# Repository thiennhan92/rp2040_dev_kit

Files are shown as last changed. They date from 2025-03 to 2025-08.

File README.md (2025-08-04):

# RP2040 Development Board

This is a custom development board based on the Raspberry Pi RP2040 microcontroller. It integrates essential peripherals for embedded systems prototyping, including USB, Ethernet, RGB LEDs, sensors, and storage. The design is accompanied by validated firmware that supports all core hardware features.

---
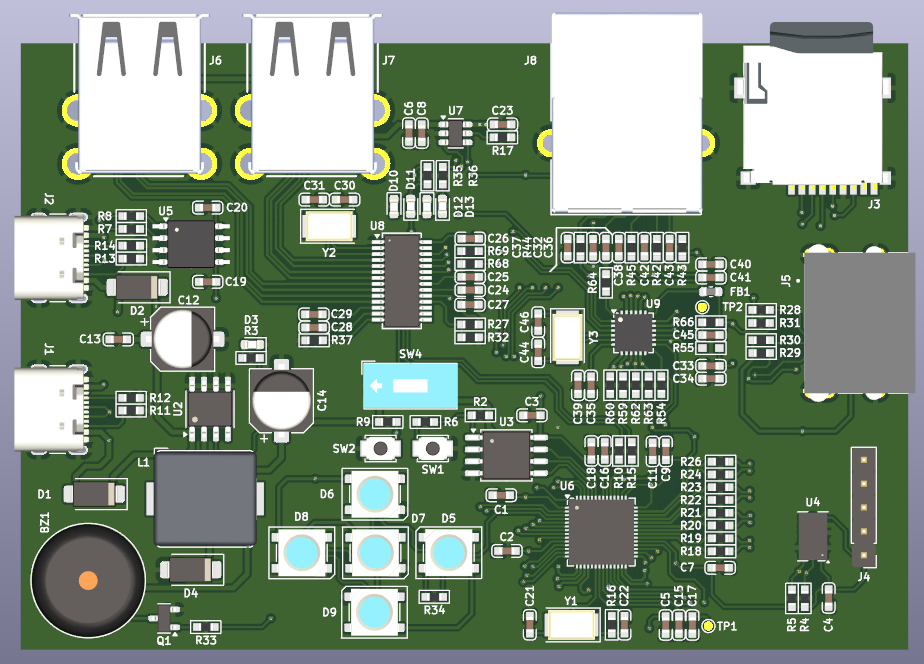
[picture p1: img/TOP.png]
RP2040 Dev Kit - Top View

## 🧩 Features

- **Microcontroller**: Raspberry Pi RP2040 (dual-core ARM Cortex-M0+)
- **Power Management**:
  - XL1509-3.3 Buck Converter
  - CH217K USB Power Switch
- **USB Interface**:
  - CH340N USB-to-Serial
  - Dual USB ports for host and device roles
- **Networking**:
  - LAN8720A Ethernet PHY (RMII)
  - RJ45 connector (HR911105A)
- **Storage**:
  - MicroSD card 
  - W25Q128FV QSPI Flash
- **Sensors**:
  - ADXL345 3-Axis Accelerometer (I²C/SPI configurable)
- **User Interface**:
  - Daisy-chained WS2812-compatible RGB LEDs
  - Onboard buzzer
  - Status LEDs (Ethernet activity)
- **Debugging**:
  - SWD interface
  - USB bootloader support
- **Expansion**:
  - HDMI-style connector (repurposed for GPIO)
  - Multiple GPIO headers and DIP switches

---

## ✅ Firmware Validation

The firmware has been **fully validated** and supports all major board features.  
*(Please check with Arduino and Pico SDK examples)*

The firmware has been fully validated and supports all major board features:

- [x] **USB Host/Device** – Detection and communication
- [x] **Ethernet** – Connectivity via LAN8720A
- [x] **MicroSD** – FAT filesystem read/write
- [x] **RGB LEDs** – WS2812-compatible LED control
- [x] **ADXL345** – Sensor readout over I²C
- [x] **QSPI Flash** – W25Q128FV access
- [x] **Buzzer & GPIO** – Output control and signal handling
- [x] **HDMI** - Digital video signal rendering tested
- [x] **Bootloader & SWD** – Debugging and firmware upload

© 2025 – RP2040 Dev Board Project. All rights reserved.

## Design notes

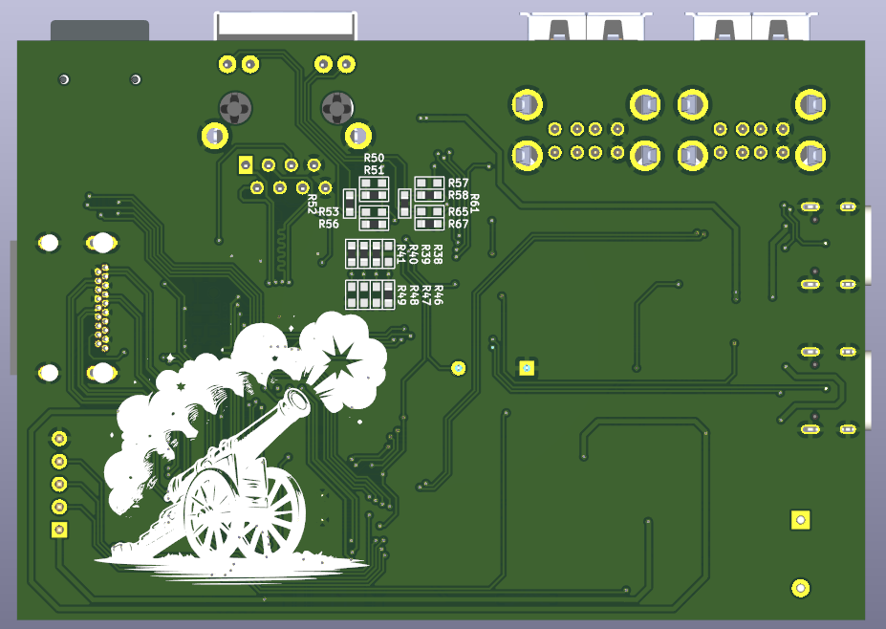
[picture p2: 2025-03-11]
img/BOT.png

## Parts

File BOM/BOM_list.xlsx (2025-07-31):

Id | Designator | Footprint | Quantity | Designation
1 | SW2,SW1 | SW_SPST_B3U-1000P | 2 | SW_SPST_3x4mm | https://www.thegioiic.com/nut-nhan-3x4mm-cao-2-5mm-2-chan-smd
2 | Y2,Y1 | Crystal_SMD_5032-2Pin_5.0x3.2mm | 2 | 12MHz
3 | Y3 | Crystal_SMD_5032-2Pin_5.0x3.2mm | 1 | 25MHz
4 | BZ1 | Buzzer_12x9.5RM7.6 | 1 | Buzzer 1209
5 | L1 | L_Bourns_SRP1038C_10.0x10.0mm | 1 | CDRH104/68uH
6 | Q1 | SOT-23 | 1 | SI2300DS
7 | SW4 | SW_DIP_01_Slide_W7.62mm_P2.54mm | 1 | SW_DIP_x01
8 | FB1 | L_0603_1608Metric | 1 | CBG160808U601T
9 | U2 | SOIC-8_3.9x4.9mm_P1.27mm | 1 | XL1509-3.3
10 | U3 | SOIC-8_5.23x5.23mm_P1.27mm | 1 | W25Q128FVSG
11 | U4 | LGA-14_3x5mm_P0.8mm | 1 | ADXL345
12 | U5 | SOP-8_3.9x4.9mm_P1.27mm | 1 | CH340N
13 | U6 | QFN-56-1EP_7x7mm_P0.4mm | 1 | RP2040
14 | U7 | SOT-23-6 | 1 | CH217K | https://linhkienthuduc.com/san-pham/ch217k-ic-bao-ve-usb-current-limiting-power-distribution-wch/
15 | U8 | SSOP-28_3.9x9.9mm_P0.635mm | 1 | FE1.1s | https://shopee.vn/product/1152770645/24613658217?gad_source=1
16 | U9 | VQFN-24-1EP_4x4mm_P0.5mm | 1 | LAN8720A
17 | J1,J2 | USB_C_Receptacle_GCT_USB4105 | 2 | USB4105-GF-A | https://www.thegioiic.com/cong-usb-cai-3-1-type-c-16-chan-thang-dan-smd
18 | J3 | MiSD-PP-9P-V2 | 1 | Micro_SD_Card | https://www.thegioiic.com/misd-pp-9p-v2-khay-the-nho-microsd-9-chan-push-push
19 | J5 | CNCTECH_2000-1-1-20-00-BK | 1 | 10029449-111RLF | https://www.thegioiic.com/cong-hdmi-cai-type-a-19-chan-vuong-goc
20 | J7,J6 | MOLEX_USB_67298-4090 | 2 | USB1035-GF-P-0-B-B | https://www.thegioiic.com/cong-usb-cai-doi-2-0-type-a-8-chan-cong-90-do
21 | J8 | RJ45_HR911105A | 1 | HR911105A
22 | C32,C26,C15,C5,C23,C28,C19,C3,C16,C33,C1,C2,C45, C11,C7,C27,C4,C6,C9,C20 | C0603_HandSoldering | 20 | C0603/0.1uF
23 | C41,C29,C34,C24,C39,C8,C25 | C0603_HandSoldering | 7 | C0603/10uF
24 | C21,C44,C38,C30,C46,C31,C42,C22,C37,C43 | C0603_HandSoldering | 10 | C0603/10pF
25 | C12,C14 | CP_Elec_6.3x7.7 | 2 | CP/220uH/16V
26 | C18,C17,C13 | C0603_HandSoldering | 3 | C0603/1uF
27 | C36 | C0603_HandSoldering | 1 | C0603/22nF
28 | C40,C35 | C0603_HandSoldering | 2 | C0603/470pF
29 | D1,D4,D2 | D_SMA | 3 | SS34
30 | D8,D9,D7,D6,D5 | LED_WS2812B_PLCC4_5.0x5.0mm | 5 | WS2812B
31 | D10,D13,D12,D3,D11 | LED_0603_1608Metric | 5 | LED_green
32 | R62,R7,R63,R10,R60,R15,R8,R59 | R0603_HandSoldering | 8 | R0603/22R
33 | R34,R24,R18,R19,R28,R26,R20,R22,R23,R21,R56,R67 | R0603_HandSoldering | 12 | R0603/200R
34 | R11,R14,R68,R27,R2,R9,R13,R12,R69,R66,R46,R52, R41,R39,R40,R61 | R0603_HandSoldering | 16 | R0603/5.6K
35 | R29,R36,R30,R31,R37,R35,R4,R5 | R0603_HandSoldering | 8 | R0603/2.7K
36 | R6,R3,R54,R33,R16 | R0603_HandSoldering | 5 | R0603/1K
37 | R64 | R0603_HandSoldering | 1 | R0603/12.1K/1%
38 | R32,R17 | R0603_HandSoldering | 2 | R0603/30.1K/1%
39 | R44,R43,R45,R42 | R0603_HandSoldering | 4 | R0603/49.9R/1%
40 | R58,R51 | R0603_HandSoldering | 2 | R0603/0R
41 | R55,R48,R38,R53,R49,R50,R47,R65,R57 | R0603_HandSoldering | 9 | R0603/NA

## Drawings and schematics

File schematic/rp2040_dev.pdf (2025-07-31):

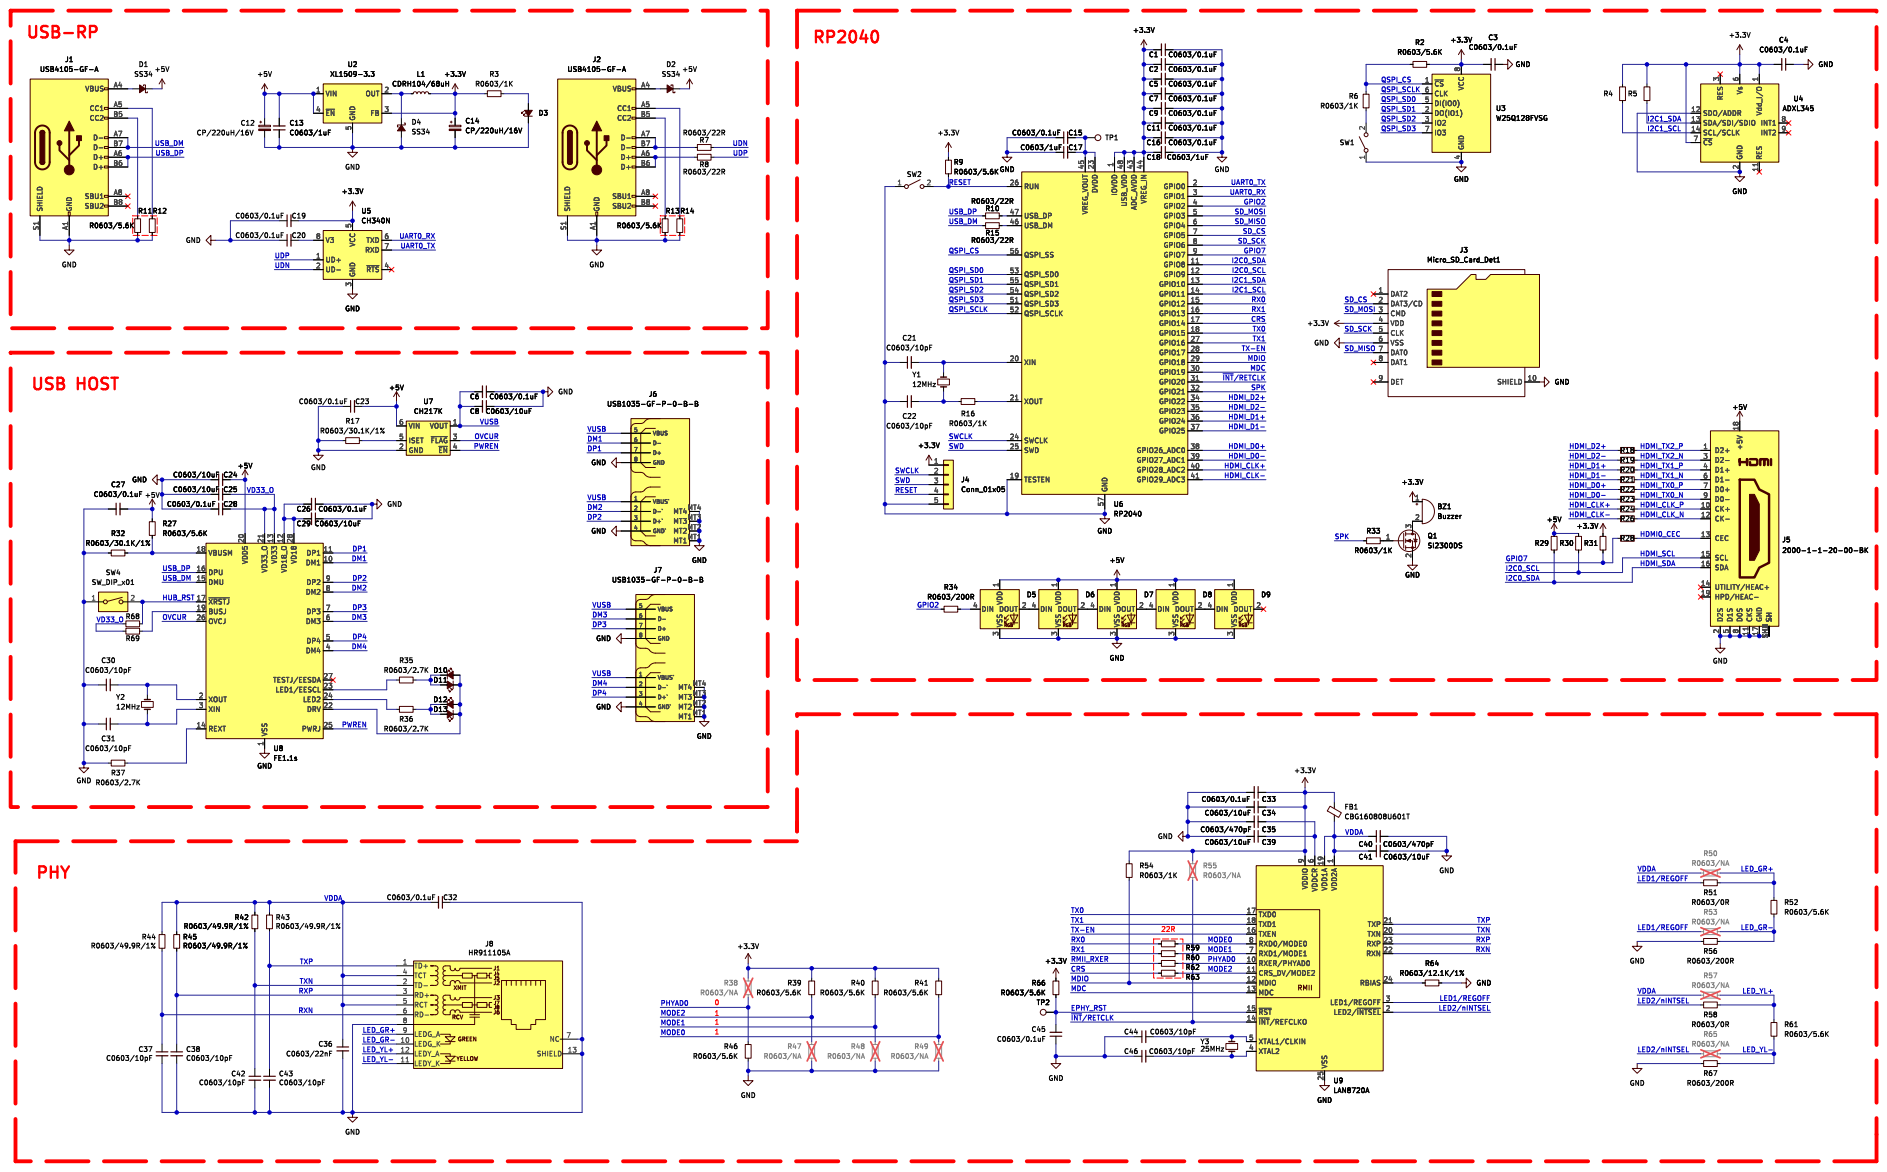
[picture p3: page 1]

3 TXD 6 RXD 7 ~{RTS}4 R13 C14 CP/220uH/16V D3

3 DOUT 2 D8 RMII TXD0 17 TXD1 18 TXEN 16 RXD0/MODE0 8 RXD1/MODE1 7 RXER/PHYAD0 10 CRS_DV/MODE2 11 MDIO 12 MDC 13 ~{RST} 15 ~{INT}/REFCLKO 14 XTAL1/CLKIN 5 XTAL2 4 VDDIO

J8J6 TD+ 1 TCT 4 TD- 2 RD+ 3 RCT 5 RD- 6

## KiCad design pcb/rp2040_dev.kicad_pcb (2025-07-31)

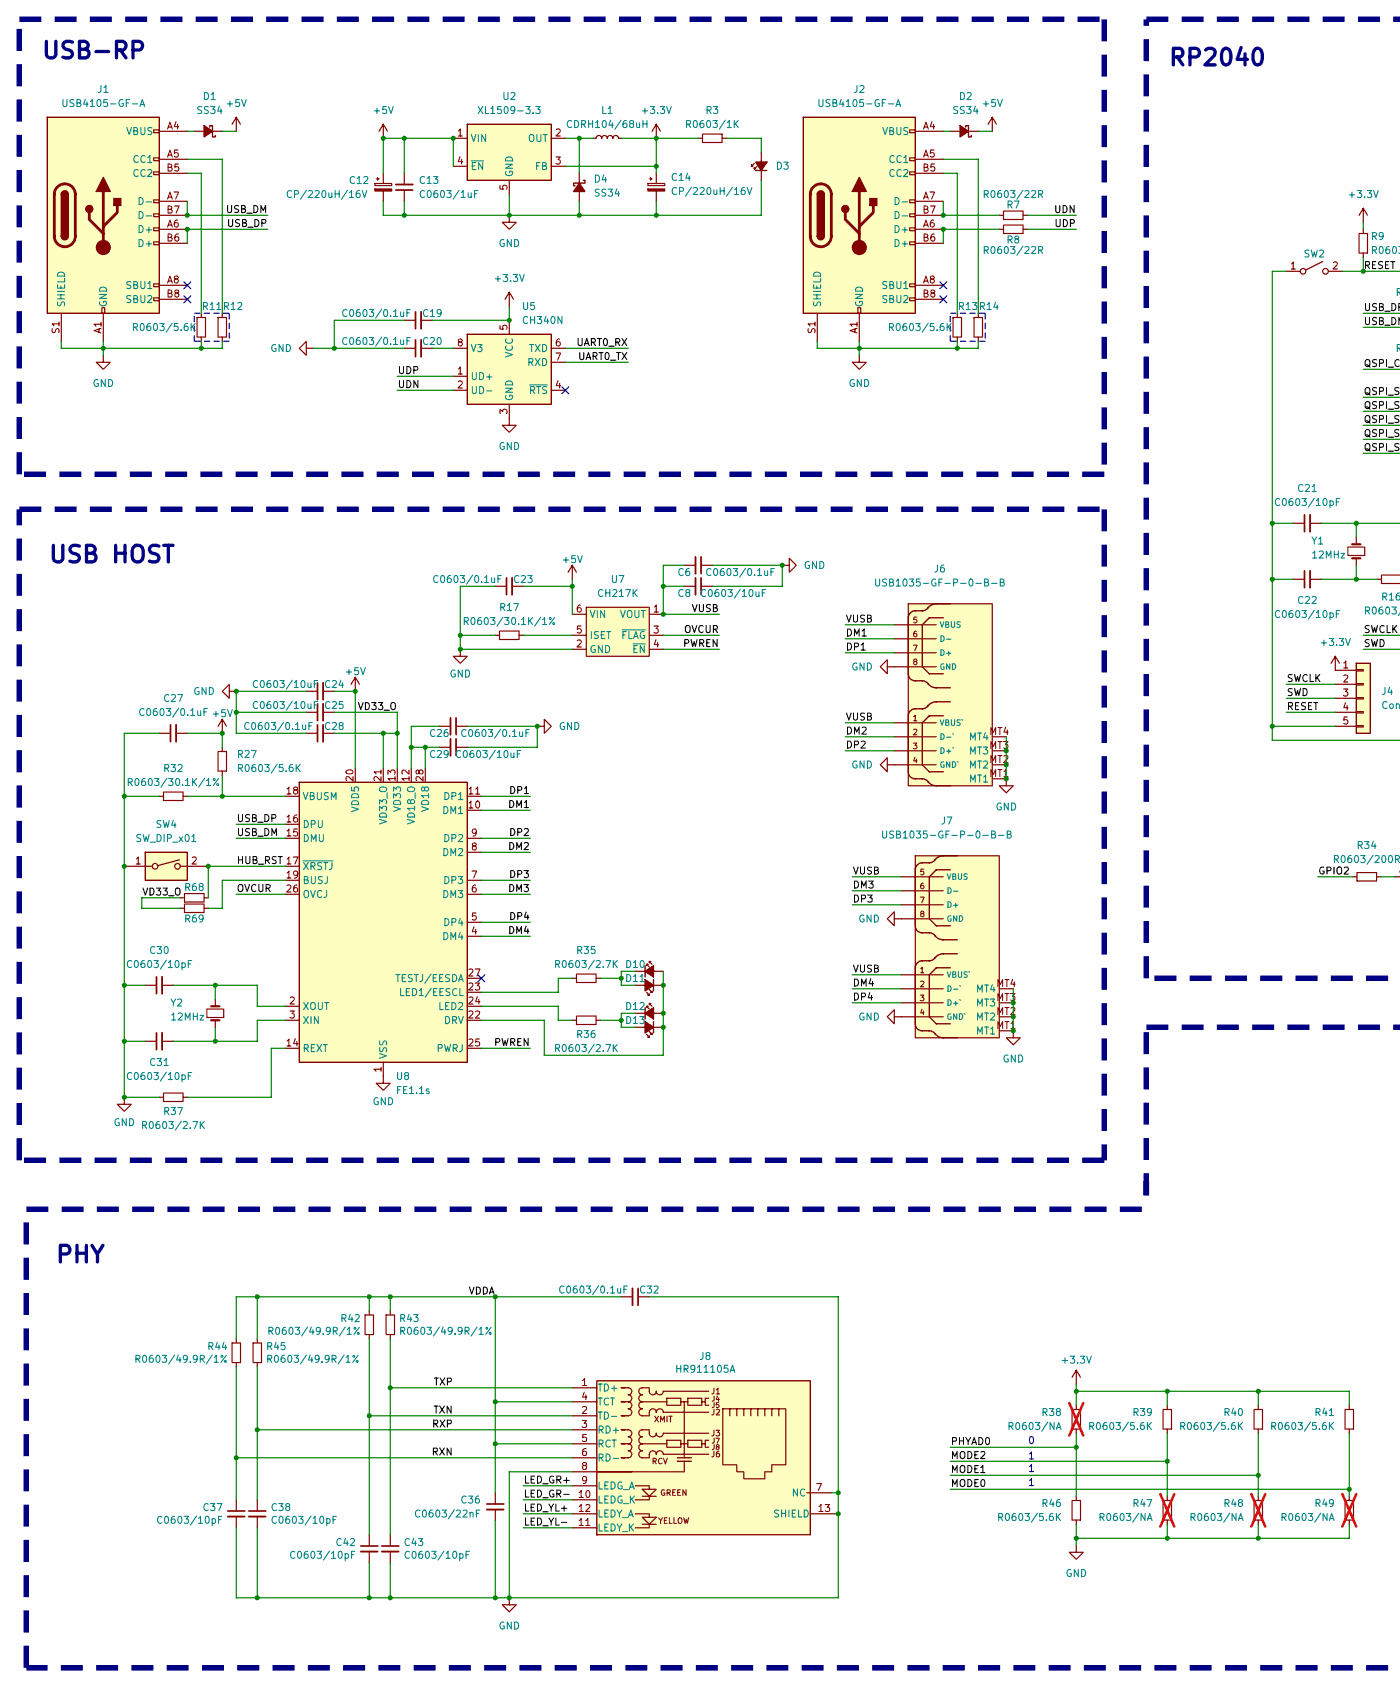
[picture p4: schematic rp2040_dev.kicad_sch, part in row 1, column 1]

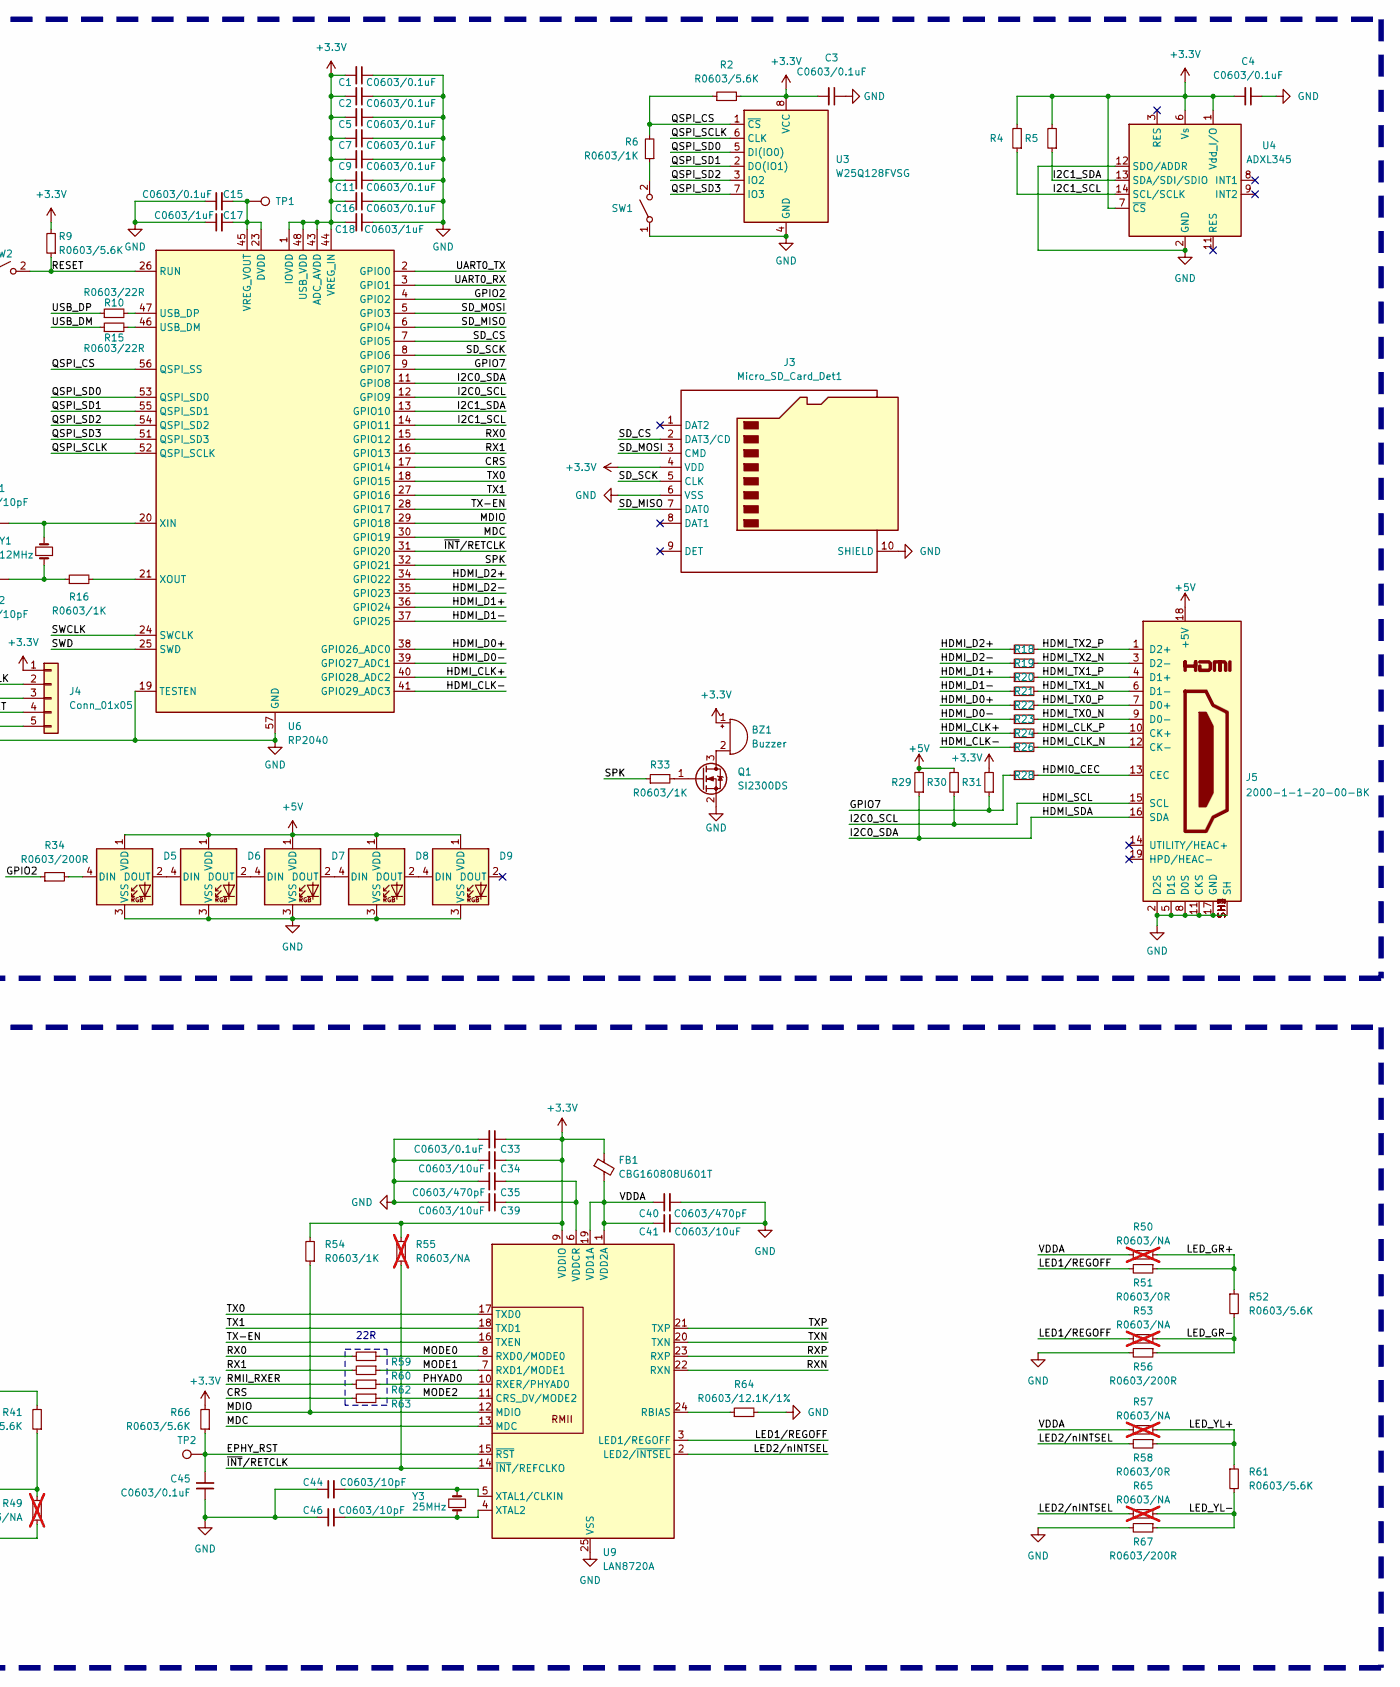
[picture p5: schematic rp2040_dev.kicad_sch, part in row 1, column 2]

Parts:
BZ1: Buzzer; Buzzer_12x9.5RM7.6
C1, C2, C3, C4, C5, C6, C7, C9, C11, C15, C16, C19, C20, C23, C26, C27, C28, C32, C33, C45: C0603/0.1uF; C0603_HandSoldering
C8, C24, C25, C29, C34, C39, C41: C0603/10uF; C0603_HandSoldering
C12, C14: CP/220uH/16V; CP_Elec_6.3x7.7
C13, C17, C18: C0603/1uF; C0603_HandSoldering
C21, C22, C30, C31: C0603/10pF; C0603_HandSoldering; PartNumber 0603N270K250CT
C35, C40: C0603/470pF; C0603_HandSoldering
C36: C0603/22nF; C0603_HandSoldering
C37, C38, C42, C43, C44, C46: C0603/10pF; C0603_HandSoldering
D1, D2, D4: SS34; D_SMA
D3, D10, D11, D12, D13: LED_green; LED_0603_1608Metric
D5, D6, D7, D8, D9: WS2812B; LED_WS2812B_PLCC4_5.0x5.0mm_P3.2mm
FB1: CBG160808U601T; L_0603_1608Metric
J1, J2: USB4105-GF-A; USB_C_Receptacle_GCT_USB4105-xx-A_16P_TopMnt_Horizontal; PartNumber USB4105-GF-A
J3: Micro_SD_Card_Det1; MiSD-PP-9P-V2
J4: Conn_01x05; PinHeader_1x05_P2.54mm_Vertical
J5: 2000-1-1-20-00-BK; CNCTECH_2000-1-1-20-00-BK; PARTREV A
J6, J7: USB1035-GF-P-0-B-B; MOLEX_USB_67298-4090
J8: HR911105A; RJ45_HR911105A
L1: CDRH104/68uH; L_Bourns_SRP1038C_10.0x10.0mm
Q1: SI2300DS; SOT-23; PartNumber SI2302DDS-T1-GE3
R2, R9, R11, R12, R13, R14, R27, R39, R40, R41, R46, R52, R61, R66, R68, R69: R0603/5.6K; R0603_HandSoldering
R3, R6, R16, R33, R54: R0603/1K; R0603_HandSoldering
R4, R5, R29, R30, R31, R35, R36, R37: R0603/2.7K; R0603_HandSoldering
R7, R8, R10, R15, R59, R60, R62, R63: R0603/22R; R0603_HandSoldering
R17, R32: R0603/30.1K/1%; R0603_HandSoldering
R18, R19, R20, R21, R22, R23, R24, R26, R28, R34, R56, R67: R0603/200R; R0603_HandSoldering
R38, R47, R48, R49, R50, R53, R55, R57, R65: R0603/NA; R0603_HandSoldering; not fitted
R42, R43, R44, R45: R0603/49.9R/1%; R0603_HandSoldering
R51, R58: R0603/0R; R0603_HandSoldering
R64: R0603/12.1K/1%; R0603_HandSoldering
SW1, SW2: SW_SPST_3x4mm; SW_SPST_B3U-1000P
SW4: SW_DIP_x01; SW_DIP_SPSTx01_Slide_9.78x4.72mm_W7.62mm_P2.54mm
TP1, TP2: TestPoint; TestPoint_Pad_D1.0mm
U2: XL1509-3.3; SOIC-8_3.9x4.9mm_P1.27mm
U3: W25Q128FVSG; SOIC-8_5.23x5.23mm_P1.27mm; PartNumber W25Q128JVS
U4: ADXL345; LGA-14_3x5mm_P0.8mm_LayoutBorder1x6y
U5: CH340N; SOP-8_3.9x4.9mm_P1.27mm
U6: RP2040; QFN-56-1EP_7x7mm_P0.4mm_EP3.2x3.2mm_ThermalVias; PartNumber RP2040
U7: CH217K; SOT-23-6
U8: FE1.1s; SSOP-28_3.9x9.9mm_P0.635mm
U9: LAN8720A; VQFN-24-1EP_4x4mm_P0.5mm_EP2.5x2.5mm
Y1, Y2: 12MHz; Crystal_SMD_5032-2Pin_5.0x3.2mm
Y3: 25MHz; Crystal_SMD_5032-2Pin_5.0x3.2mm

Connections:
+3.3V: BZ1.1 (-), C1.2, C2.2, C3.2, C4.2, C5.2, C7.2, C9.2, C11.2, C14.1, C16.2, C18.2, C19.2, C33.1, C34.1, FB1.1, J3.4 (VDD), J4.1, L1.2, R2.2, R3.2, R4.2, R5.2, R9.2, R31.2, R38.2, R39.2, R40.2, R41.2, R54.2, R55.2, R66.2, U2.3 (FB), U3.8 (VCC), U4.1 (Vdd_I/O), U4.6 (Vs), U4.7 (~CS), U5.5 (VCC), U6.1 (IOVDD), U6.10 (IOVDD), U6.22 (IOVDD), U6.33 (IOVDD), U6.42 (IOVDD), U6.43 (ADC_AVDD), U6.44 (VREG_IN), U6.48 (USB_VDD), U6.49 (IOVDD), U9.9 (VDDIO)
+5V: C12.1, C13.2, C23.2, C24.2, C27.2, D1.1 (K), D2.1 (K), D5.1 (VDD), D6.1 (VDD), D7.1 (VDD), D8.1 (VDD), D9.1 (VDD), J5.18 (+5V), R27.2, R29.2, R30.2, U2.1 (VIN), U2.4 (~EN), U7.6 (VIN), U8.20 (VDD5)
/CRS: R63.2, U6.17 (GPIO14)
/DM1: J6.6 (D-), U8.10 (DM1)
/DM2: J6.2 (D-`), U8.8 (DM2)
/DM3: J7.6 (D-), U8.6 (DM3)
/DM4: J7.2 (D-`), U8.4 (DM4)
/DP1: J6.7 (D+), U8.11 (DP1)
/DP2: J6.3 (D+`), U8.9 (DP2)
/DP3: J7.7 (D+), U8.7 (DP3)
/DP4: J7.3 (D+`), U8.5 (DP4)
/EPHY_RST: C45.2, R66.1, TP2.1, U9.15 (~RST)
/GPIO2: R34.1, U6.4 (GPIO2)
/GPIO7: R28.1, R31.1, U6.9 (GPIO7)
/HDMI0_CEC: J5.13 (CEC), R28.2
/HDMI_CLK+: R24.1, U6.40 (GPIO28_ADC2)
/HDMI_CLK-: R26.1, U6.41 (GPIO29_ADC3)
/HDMI_CLK_N: J5.12 (CK-), R26.2
/HDMI_CLK_P: J5.10 (CK+), R24.2
/HDMI_D0+: R22.1, U6.38 (GPIO26_ADC0)
/HDMI_D0-: R23.1, U6.39 (GPIO27_ADC1)
/HDMI_D1+: R20.1, U6.36 (GPIO24)
/HDMI_D1-: R21.1, U6.37 (GPIO25)
/HDMI_D2+: R18.1, U6.34 (GPIO22)
/HDMI_D2-: R19.1, U6.35 (GPIO23)
/HDMI_SCL: J5.15 (SCL), R30.1, U6.12 (GPIO9)
/HDMI_SDA: J5.16 (SDA), R29.1, U6.11 (GPIO8)
/HDMI_TX0_N: J5.9 (D0-), R23.2
/HDMI_TX0_P: J5.7 (D0+), R22.2
/HDMI_TX1_N: J5.6 (D1-), R21.2
/HDMI_TX1_P: J5.4 (D1+), R20.2
/HDMI_TX2_N: J5.3 (D2-), R19.2
/HDMI_TX2_P: J5.1 (D2+), R18.2
/HUB_RST: R68.2, SW4.2, U8.17 (~XRSTJ)
/I2C1_SCL: R4.1, U4.14 (SCL/SCLK), U6.14 (GPIO11)
/I2C1_SDA: R5.1, U4.13 (SDA/SDI/SDIO), U6.13 (GPIO10)
/LED1/REGOFF: R51.2, R53.2, U9.3 (LED1/REGOFF)
/LED2/nINTSEL: R58.2, R65.2, U9.2 (LED2/~INTSEL)
/LED_GR+: J8.9 (LEDG_A), R50.1, R51.1, R52.1
/LED_GR-: J8.10 (LEDG_K), R52.2, R53.1, R56.1
/LED_YL+: J8.12 (LEDY_A), R57.1, R58.1, R61.1
/LED_YL-: J8.11 (LEDY_K), R61.2, R65.1, R67.1
/MDC: U6.30 (GPIO19), U9.13 (MDC)
/MDIO: R54.1, U6.29 (GPIO18), U9.12 (MDIO)
/MODE0: R41.1, R49.2, R59.1, U9.8 (RXD0/MODE0)
/MODE1: R40.1, R48.2, R60.1, U9.7 (RXD1/MODE1)
/MODE2: R39.1, R47.2, R63.1, U9.11 (CRS_DV/MODE2)
/OVCUR: U7.3 (~FLAG), U8.26 (OVCJ)
/PHYAD0: R38.1, R46.2, R62.1, U9.10 (RXER/PHYAD0)
/PWREN: U7.4 (~EN), U8.25 (PWRJ)
/QSPI_CS: R2.1, R6.2, U3.1 (~CS), U6.56 (QSPI_SS)
/QSPI_SCLK: U3.6 (CLK), U6.52 (QSPI_SCLK)
/QSPI_SD0: U3.5 (DI(IO0)), U6.53 (QSPI_SD0)
/QSPI_SD1: U3.2 (DO(IO1)), U6.55 (QSPI_SD1)
/QSPI_SD2: U3.3 (IO2), U6.54 (QSPI_SD2)
/QSPI_SD3: U3.7 (IO3), U6.51 (QSPI_SD3)
/RESET: J4.4, R9.1, SW2.2 (B), U6.26 (RUN)
/RMII_RXER: R62.2
/RX0: R59.2, U6.15 (GPIO12)
/RX1: R60.2, U6.16 (GPIO13)
/RXN: C37.1, J8.6 (RD-), R44.2, U9.22 (RXN)
/RXP: C38.1, J8.3 (RD+), R45.2, U9.23 (RXP)
/SD_CS: J3.2 (DAT3/CD), U6.7 (GPIO5)
/SD_MISO: J3.7 (DAT0), U6.6 (GPIO4)
/SD_MOSI: J3.3 (CMD), U6.5 (GPIO3)
/SD_SCK: J3.5 (CLK), U6.8 (GPIO6)
/SPK: R33.1, U6.32 (GPIO21)
/SWCLK: J4.2, U6.24 (SWCLK)
/SWD: J4.3, U6.25 (SWD)
/TX0: U6.18 (GPIO15), U9.17 (TXD0)
/TX1: U6.27 (GPIO16), U9.18 (TXD1)
/TX-EN: U6.28 (GPIO17), U9.16 (TXEN)
/TXN: C42.1, J8.2 (TD-), R42.2, U9.20 (TXN)
/TXP: C43.1, J8.1 (TD+), R43.2, U9.21 (TXP)
/UART0_RX: U5.6 (TXD), U6.3 (GPIO1)
/UART0_TX: U5.7 (RXD), U6.2 (GPIO0)
/UDN: R7.2, U5.2 (UD-)
/UDP: R8.2, U5.1 (UD+)
/USB_DM: J1.A7 (D-), J1.B7 (D-), R15.1, U8.15 (DMU)
/USB_DP: J1.A6 (D+), J1.B6 (D+), R10.1, U8.16 (DPU)
/VD33_O: C25.2, C28.2, R68.1, R69.1, U8.13 (VD33), U8.21 (VD33_O)
/VDDA: C32.2, C36.1, C40.1, C41.1, FB1.2, J8.4 (TCT), J8.5 (RCT), R42.1, R43.1, R44.1, R45.1, R50.2, R57.2, U9.1 (VDD2A), U9.19 (VDD1A)
/VUSB: C6.2, C8.2, J6.1 (VBUS`), J6.5 (VBUS), J7.1 (VBUS`), J7.5 (VBUS), U7.1 (VOUT)
/~INT/RETCLK: R55.1, U6.31 (GPIO20), U9.14 (~INT/REFCLKO)
GND: C1.1, C2.1, C3.1, C4.1, C5.1, C6.1, C7.1, C8.1, C9.1, C11.1, C12.2, C13.1, C14.2, C15.1, C16.1, C17.1, C18.1, C19.1, C20.1, C21.1, C22.1, C23.1, C24.1, C25.1, C26.1, C27.1, C28.1, C29.1, C30.1, C31.1, C32.1, C33.2, C34.2, C35.2, C36.2, C37.2, C38.2, C39.2, C40.2, C41.2, C42.2, C43.2, C44.1, C45.1, C46.1, D3.1 (K), D4.2 (A), D5.3 (VSS), D6.3 (VSS), D7.3 (VSS), D8.3 (VSS), D9.3 (VSS), J1.A1 (GND), J1.A12 (GND), J1.B1 (GND), J1.B12 (GND), J1.S1 (SHIELD), J2.A1 (GND), J2.A12 (GND), J2.B1 (GND), J2.B12 (GND), J2.S1 (SHIELD), J3.6 (VSS), J3.10 (SHIELD), J4.5, J5.2 (D2S), J5.5 (D1S), J5.8 (D0S), J5.11 (CKS), J5.17 (GND), J5.SH1 (SH), J5.SH2 (SH), J5.SH3 (SH), J5.SH4 (SH), J6.4 (GND`), J6.8 (GND), J6.MT1, J6.MT2, J6.MT3, J6.MT4, J7.4 (GND`), J7.8 (GND), J7.MT1, J7.MT2, J7.MT3, J7.MT4, J8.7 (NC), J8.8, J8.13 (SHIELD), Q1.2 (S), R11.2, R12.2, R13.2, R14.2, R17.1, R32.1, R37.1, R46.1, R47.1, R48.1, R49.1, R56.2, R64.2, R67.2, SW1.1 (A), SW2.1 (A), SW4.1, U2.5 (GND), U2.6 (GND), U2.7 (GND), U2.8 (GND), U3.4 (GND), U4.2 (GND), U4.4 (GND), U4.5 (GND), U4.12 (SDO/ADDR), U5.3 (GND), U6.19 (TESTEN), U6.57 (GND), U7.2 (GND), U8.1 (VSS), U9.25 (VSS)
unnamed: BZ1.2 (+), Q1.3 (D)
unnamed: C22.2, R16.1, Y1.1
unnamed: D1.2 (A), J1.A4 (VBUS), J1.A9 (VBUS), J1.B4 (VBUS), J1.B9 (VBUS)
unnamed: D2.2 (A), J2.A4 (VBUS), J2.A9 (VBUS), J2.B4 (VBUS), J2.B9 (VBUS)
unnamed: D3.2 (A), R3.1
unnamed: D4.1 (K), L1.1, U2.2 (OUT)
unnamed: D5.4 (DIN), R34.2
unnamed: D5.2 (DOUT), D6.4 (DIN)
unnamed: D6.2 (DOUT), D7.4 (DIN)
unnamed: D7.2 (DOUT), D8.4 (DIN)
unnamed: D8.2 (DOUT), D9.4 (DIN)
unnamed: D10.2 (A), D11.1 (K), D12.2 (A), D13.1 (K), U8.22 (DRV)
unnamed: D10.1 (K), D11.2 (A), R35.2
unnamed: D12.1 (K), D13.2 (A), R36.2
unnamed: J1.A5 (CC1), R12.1
unnamed: J1.B5 (CC2), R11.1
unnamed: J2.A5 (CC1), R14.1
unnamed: J2.B5 (CC2), R13.1
unnamed: J2.A6 (D+), J2.B6 (D+), R8.1
unnamed: J2.A7 (D-), J2.B7 (D-), R7.1
unnamed: Q1.1 (G), R33.2
unnamed: R6.1, SW1.2 (B)
unnamed: C20.2, U5.8 (V3)
unnamed: R15.2, U6.46 (USB_DM)
unnamed: R10.2, U6.47 (USB_DP)
unnamed: C15.2, C17.2, TP1.1, U6.23 (DVDD), U6.45 (VREG_VOUT), U6.50 (DVDD)
unnamed: C21.2, U6.20 (XIN), Y1.2
unnamed: R16.2, U6.21 (XOUT)
unnamed: R17.2, U7.5 (ISET)
unnamed: R69.2, U8.19 (BUSJ)
unnamed: R35.1, U8.23 (LED1/EESCL)
unnamed: R36.1, U8.24 (LED2)
unnamed: R37.2, U8.14 (REXT)
unnamed: R27.1, R32.2, U8.18 (VBUSM)
unnamed: C26.2, C29.2, U8.12 (VD18_O), U8.28 (VD18)
unnamed: C31.2, U8.3 (XIN), Y2.1
unnamed: C30.2, U8.2 (XOUT), Y2.2
unnamed: R64.1, U9.24 (RBIAS)
unnamed: C35.1, C39.1, U9.6 (VDDCR)
unnamed: C44.2, U9.5 (XTAL1/CLKIN), Y3.2
unnamed: C46.2, U9.4 (XTAL2), Y3.1

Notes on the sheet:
22R
RP2040
PHY
USB HOST
USB-RP

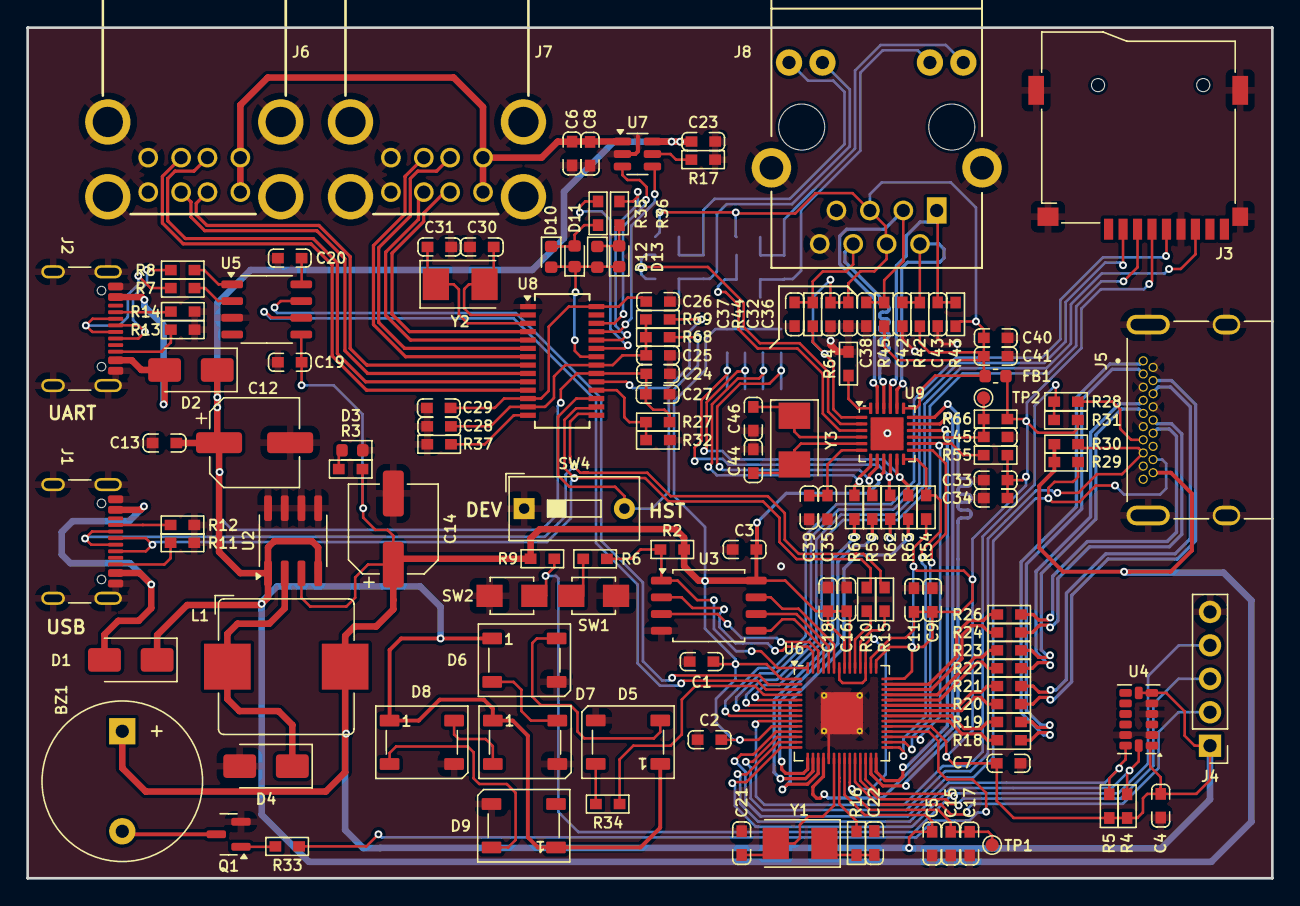
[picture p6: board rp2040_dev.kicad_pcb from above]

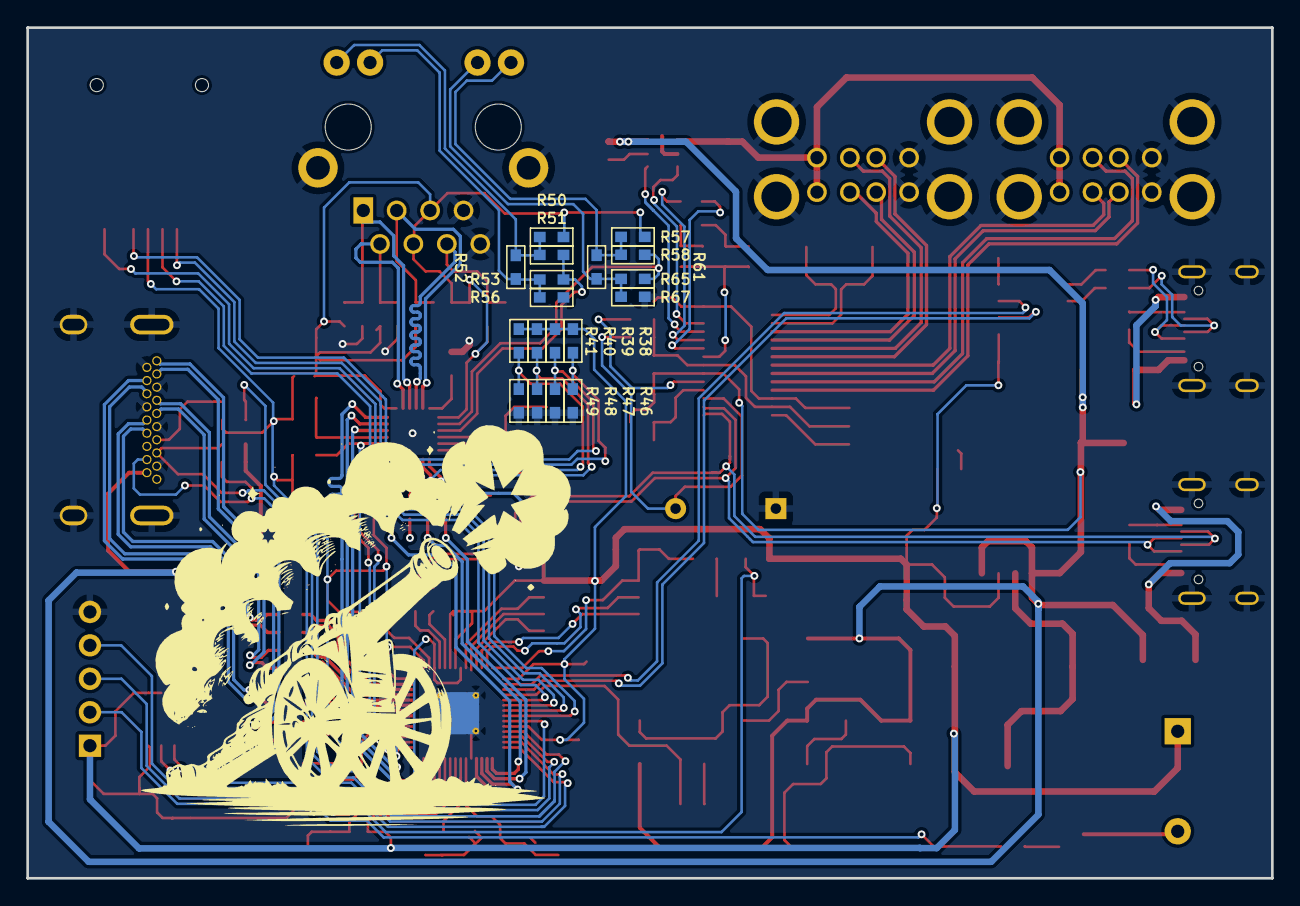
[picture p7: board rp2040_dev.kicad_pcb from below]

Board: 2 copper layers, 94.6 x 64.6 mm, 153 parts (18 on the bottom side), 125 nets.

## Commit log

2025-03-11 Initial project
    [rp2040_dev-B_Cu.gbr, rp2040_dev-B_Mask.gbr, rp2040_dev-B_Paste.gbr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]
2025-03-18 Update BOM list
    [BOM_list.xlsx, rp2040_dev.csv]
2025-07-31 Fix UART0 reversed pins
    [BOM_list.xlsx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]
2025-08-04 Add board image
